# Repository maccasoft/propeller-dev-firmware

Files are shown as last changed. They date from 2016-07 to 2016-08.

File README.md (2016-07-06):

## Propeller Development Board

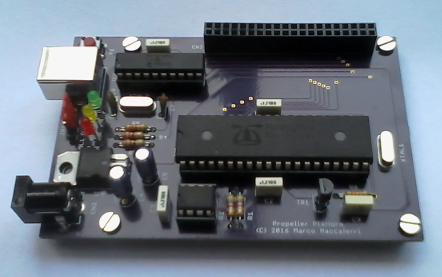
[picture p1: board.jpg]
The Board


This is my own version of a [Parallax Propeller](https://www.parallax.com) development board.

Uses a PIC microcontroller for the USB-Serial interface, can be powered from either USB or a dedicated power source, includes
an EEPROM to store the program and data, and provides a 2x20 pin header exposing all 32 I/O pins from the Propeller microcontroller,
power and control lines.

Compatible with all standard Propeller development tools.

**Parts List**

* R1 = 4.700 ohm 1/4 watt  
* R2 = 4.700 ohm 1/4 watt  
* R3 = 220 ohm 1/4 watt  
* R4 = 220 ohm 1/4 watt  
* R5 = 220 ohm 1/4 watt  
* R6 = 33.000 ohm 1/4 watt  
* C1 = 100.000 pF poli  
* C2 = 100.000 pF poli  
* C3 = 100.000 pF poli  
* C4 = 10 uF 63v elettr.  
* C5 = 10 uF 63v elettr.  
* C6 = 100.000 pF poli  
* C7 = 27 pF disc  
* C8 = 27 pF disc  
* C9 = 10.000 pF poli  
* DL1 = Red LED  
* DL2 = Yellow LED  
* DL3 = Green LED  
* XTAL1 = 5 MHz crystal  
* XTAL2 = 12 MHz crystal  
* IC1 = P8X32A  
* IC2 = 24LC512  
* IC3 = PIC18F14K50  
* IC4 = LM1117T-3.3  
* TR1 = Transistor NPN BC547  
* CN1 = USB-B connector  
* CN2 = 2.1mm DC power connector  
* CN3 = 2x20 pin header  
* JP1 = 1x3 pin header  
* P1 =  Button  

**JP1**

Power source selection:

```
+-+  
|1| USB  
|2| VIN  
|3| EXT  
+-+  
```

short pins 1-2 to power from USB  
short pins 2-3 to power from external source.

**CN3**

From top, P0/P1 are near the PIC/USB microcontroller.

```
+-------+-------+  
|     P0|P1     |  
|     P2|P3     |  
|     P4|P5     |  
|     P6|P7     |  
|     P8|P9     |  
|    P10|P11    |  
|    P12|P13    |  
|    P14|P15    |  
|    P16|P17    |  
|    P18|P19    |  
|    P20|P21    |  
|    P22|P23    |  
|    P24|P25    |  
|    P26|P27    |  
|SDA/P29|N.C.   |  
|SCL/P28|XI     |  
| TX/P30|RTS    |  
| RX/P31|CTS    |  
|  RESET|+3.3v  |  
|    GND|VIN    |  
+-------+-------+  
```

PCBs are shared on [OSH Park](https://oshpark.com) and can be ordered from there:
[https://oshpark.com/shared_projects/KALqBSpm](https://oshpark.com/shared_projects/KALqBSpm)

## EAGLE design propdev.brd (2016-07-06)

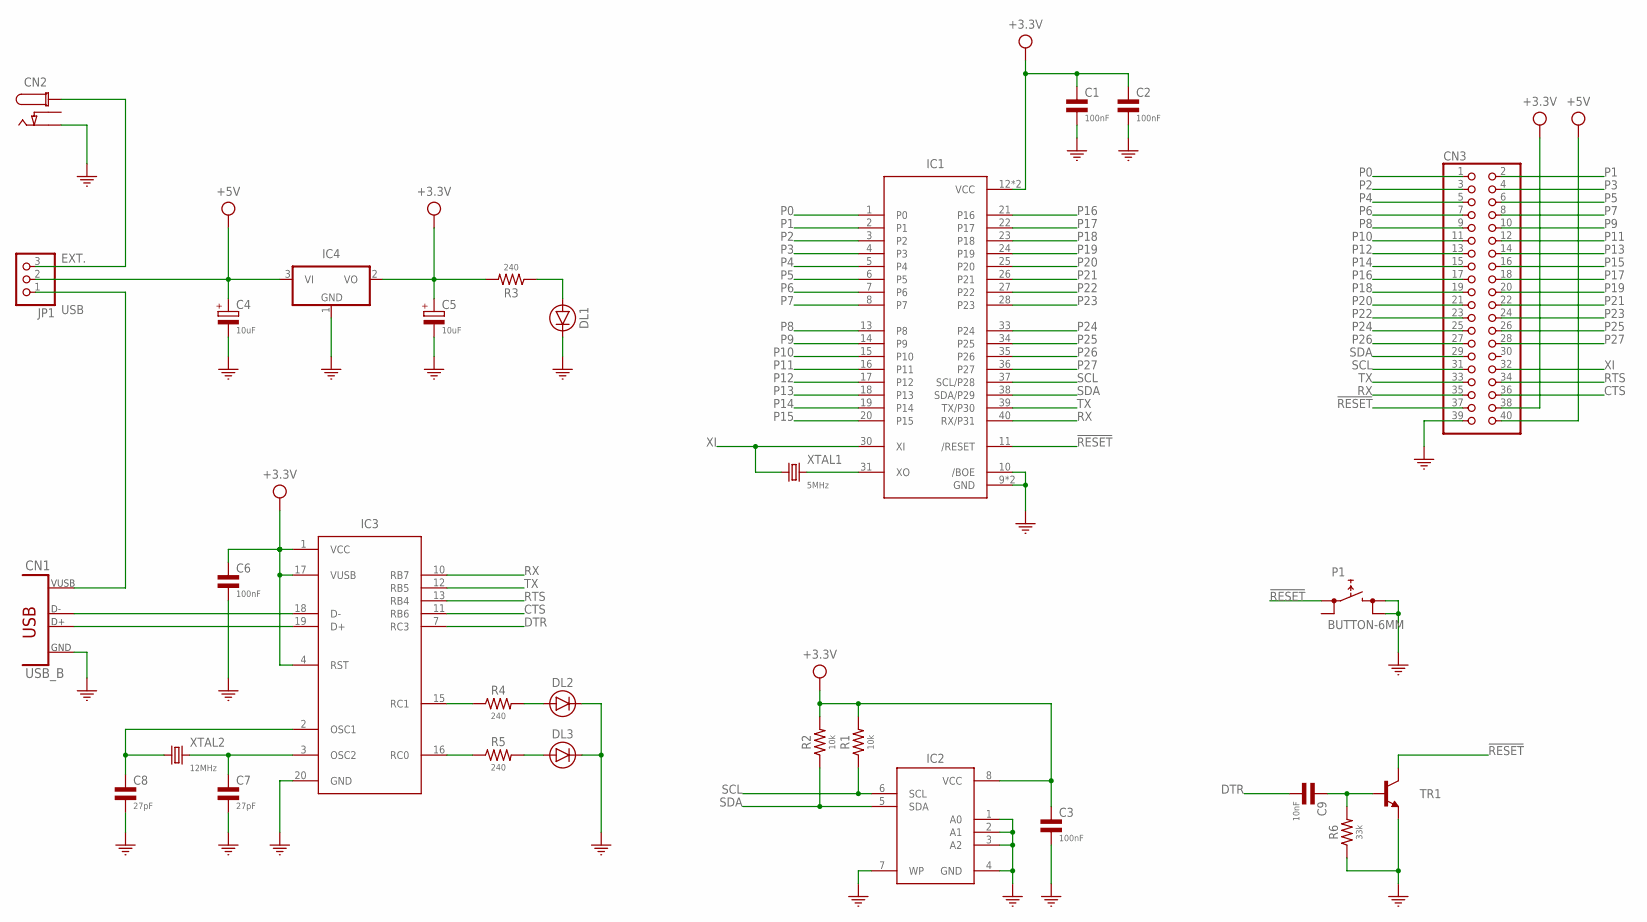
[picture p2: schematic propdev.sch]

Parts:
C1, C2, C3, C6: 100nF; C050-025X075
C4, C5: 10uF; E2,5-6
C7, C8: 27pF; C050-025X075
C9: 10nF; C050-025X075
CN1: USB_B; USB-B
CN2: DC_JACK; PJ-102A
CN3: PINHD-2X20B; 2X20B
DL1, DL2, DL3: LED-3MM; LED3MM
IC1: P8X32A; DIL40
IC2: 24LC512-I/P; DIL08
IC3: PIC18F14K50-I/P; DIL20
IC4: LM1117T-3.3; TO220H
JP1: PINHD-1X3; 1X03
P1: BUTTON-6MM; TL1105
R1, R2: 10k; 0207/10
R3, R4, R5: 240; 0207/10
R6: 33k; 0207/10
TR1: BC547; TO92
XTAL1: 5MHz; HC49/S
XTAL2: 12MHz; HC49/S

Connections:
!RESET!: CN3.37, IC1.11 (/RESET), P1.1 (0), TR1.3 (C)
+3.3V: C1.1, C2.1, C3.1, C5.+, C6.1, CN3.38, IC1.12 (VCC), IC1.32 (VCC), IC2.8 (VCC), IC3.1 (VCC), IC3.4 (RST), IC3.17 (VUSB), IC4.2 (VO), R1.2, R2.2, R3.2
+5V: C4.+, CN3.40, IC4.3 (VI), JP1.2
CTS: CN3.36, IC3.11 (RB6)
DTR: C9.2, IC3.7 (RC3)
EXT.: CN2.P1, JP1.3
GND: C1.2, C2.2, C3.2, C4.-, C5.-, C6.2, C7.2, C8.2, CN1.4 (GND), CN2.P3 (P2), CN3.39, DL1.K (C), DL2.K (C), DL3.K (C), IC1.9 (GND), IC1.10 (/BOE), IC1.29 (GND), IC2.1 (A0), IC2.2 (A1), IC2.3 (A2), IC2.4 (GND), IC2.7 (WP), IC3.20 (GND), IC4.1 (GND), P1.2 (1), P1.4 (1), R6.1, TR1.1 (E)
unnamed: IC3.16 (RC0), R5.1
unnamed: CN1.2 (D-), IC3.18 (D-)
unnamed: CN1.3 (D+), IC3.19 (D+)
unnamed: C7.1, IC3.3 (OSC2), XTAL2.2
unnamed: C8.1, IC3.2 (OSC1), XTAL2.1
unnamed: C9.1, R6.2, TR1.2 (B)
unnamed: DL2.A, R4.2
unnamed: DL3.A, R5.2
unnamed: IC3.15 (RC1), R4.1
unnamed: DL1.A, R3.1
unnamed: IC1.31 (XO), XTAL1.2
P0: CN3.1, IC1.1 (P0)
P1: CN3.2, IC1.2 (P1)
P2: CN3.3, IC1.3 (P2)
P3: CN3.4, IC1.4 (P3)
P4: CN3.5, IC1.5 (P4)
P5: CN3.6, IC1.6 (P5)
P6: CN3.7, IC1.7 (P6)
P7: CN3.8, IC1.8 (P7)
P8: CN3.9, IC1.13 (P8)
P9: CN3.10, IC1.14 (P9)
P10: CN3.11, IC1.15 (P10)
P11: CN3.12, IC1.16 (P11)
P12: CN3.13, IC1.17 (P12)
P13: CN3.14, IC1.18 (P13)
P14: CN3.15, IC1.19 (P14)
P15: CN3.16, IC1.20 (P15)
P16: CN3.17, IC1.21 (P16)
P17: CN3.18, IC1.22 (P17)
P18: CN3.19, IC1.23 (P18)
P19: CN3.20, IC1.24 (P19)
P20: CN3.21, IC1.25 (P20)
P21: CN3.22, IC1.26 (P21)
P22: CN3.23, IC1.27 (P22)
P23: CN3.24, IC1.28 (P23)
P24: CN3.25, IC1.33 (P24)
P25: CN3.26, IC1.34 (P25)
P26: CN3.27, IC1.35 (P26)
P27: CN3.28, IC1.36 (P27)
RTS: CN3.34, IC3.13 (RB4)
RX: CN3.35, IC1.40 (RX/P31), IC3.10 (RB7)
SCL: CN3.31, IC1.37 (SCL/P28), IC2.6 (SCL), R1.1
SDA: CN3.29, IC1.38 (SDA/P29), IC2.5 (SDA), R2.1
TX: CN3.33, IC1.39 (TX/P30), IC3.12 (RB5)
USB: CN1.1 (VUSB), JP1.1
XI: CN3.32, IC1.30 (XI), XTAL1.1

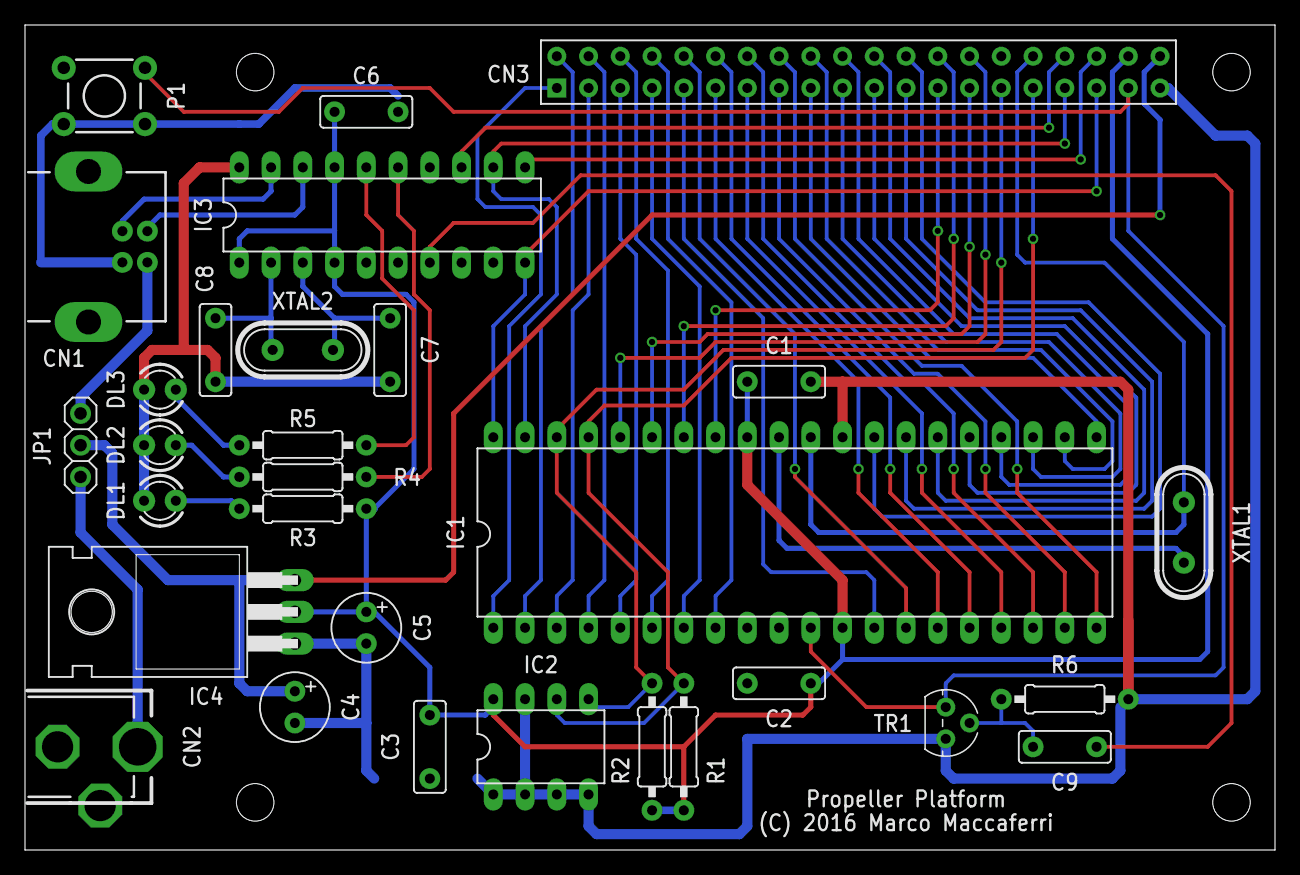
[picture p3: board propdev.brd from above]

Board: 2 copper layers, 100.0 x 66.0 mm, 30 parts (0 on the bottom side), 53 nets.

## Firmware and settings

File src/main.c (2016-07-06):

/********************************************************************
 Software License Agreement:

 The software supplied herewith by Microchip Technology Incorporated
 (the "Company") for its PIC(R) Microcontroller is intended and
 supplied to you, the Company's customer, for use solely and
 exclusively on Microchip PIC Microcontroller products. The
 software is owned by the Company and/or its supplier, and is
 protected under applicable copyright laws. All rights are reserved.
 Any use in violation of the foregoing restrictions may subject the
 user to criminal sanctions under applicable laws, as well as to
 civil liability for the breach of the terms and conditions of this
 license.

 THIS SOFTWARE IS PROVIDED IN AN "AS IS" CONDITION. NO WARRANTIES,
 WHETHER EXPRESS, IMPLIED OR STATUTORY, INCLUDING, BUT NOT LIMITED
 TO, IMPLIED WARRANTIES OF MERCHANTABILITY AND FITNESS FOR A
 PARTICULAR PURPOSE APPLY TO THIS SOFTWARE. THE COMPANY SHALL NOT,
 IN ANY CIRCUMSTANCES, BE LIABLE FOR SPECIAL, INCIDENTAL OR
 CONSEQUENTIAL DAMAGES, FOR ANY REASON WHATSOEVER.
 *******************************************************************/

/** INCLUDES *******************************************************/
#include "system.h"
#include "system_config.h"

#include "app_device_cdc_basic.h"
#include "app_led_usb_status.h"

#include "usb.h"
#include "usb_device.h"
#include "usb_device_cdc.h"

/********************************************************************
 * Function:        void main(void)
 *
 * PreCondition:    None
 *
 * Input:           None
 *
 * Output:          None
 *
 * Side Effects:    None
 *
 * Overview:        Main program entry point.
 *
 * Note:            None
 *******************************************************************/
MAIN_RETURN main(void)
{
    SYSTEM_Initialize(SYSTEM_STATE_USB_START);

    USBDeviceInit();
    USBDeviceAttach();
    
    while(1)
    {
        SYSTEM_Tasks();

        #if defined(USB_POLLING)
            // Interrupt or polling method.  If using polling, must call
            // this function periodically.  This function will take care
            // of processing and responding to SETUP transactions
            // (such as during the enumeration process when you first
            // plug in).  USB hosts require that USB devices should accept
            // and process SETUP packets in a timely fashion.  Therefore,
            // when using polling, this function should be called
            // regularly (such as once every 1.8ms or faster** [see
            // inline code comments in usb_device.c for explanation when
            // "or faster" applies])  In most cases, the USBDeviceTasks()
            // function does not take very long to execute (ex: <100
            // instruction cycles) before it returns.
            USBDeviceTasks();
        #endif


        /* If the USB device isn't configured yet, we can't really do anything
         * else since we don't have a host to talk to.  So jump back to the
         * top of the while loop. */
        if( USBGetDeviceState() < CONFIGURED_STATE )
        {
            /* Jump back to the top of the while loop. */
            continue;
        }

        /* If we are currently suspended, then we need to see if we need to
         * issue a remote wakeup.  In either case, we shouldn't process any
         * keyboard commands since we aren't currently communicating to the host
         * thus just continue back to the start of the while loop. */
        if( USBIsDeviceSuspended()== true )
        {
            /* Jump back to the top of the while loop. */
            continue;
        }

        //Application specific tasks
        APP_DeviceCDCEmulatorTasks();

    }//end while
}//end main




bool USER_USB_CALLBACK_EVENT_HANDLER(USB_EVENT event, void *pdata, uint16_t size)
{
    switch( (int) event )
    {
        case EVENT_TRANSFER:
            break;

        case EVENT_SOF:
            /* We are using the SOF as a timer to time the LED indicator.  Call
             * the LED update function here. */
            APP_LEDUpdateUSBStatus();
            break;

        case EVENT_SUSPEND:
            /* Update the LED status for the suspend event. */
            APP_LEDUpdateUSBStatus();
            break;

        case EVENT_RESUME:
            /* Update the LED status for the resume event. */
            APP_LEDUpdateUSBStatus();
            break;

        case EVENT_CONFIGURED:
            /* When the device is configured, we can (re)initialize the 
             * demo code. */
            APP_DeviceCDCEmulatorInitialize();
            break;

        case EVENT_SET_DESCRIPTOR:
            break;

        case EVENT_EP0_REQUEST:
            /* We have received a non-standard USB request.  The HID driver
             * needs to check to see if the request was for it. */
            USBCheckCDCRequest();
            break;

        case EVENT_BUS_ERROR:
            break;

        case EVENT_TRANSFER_TERMINATED:
            break;

        default:
            break;
    }
    return true;
}

/*******************************************************************************
 End of File
*/

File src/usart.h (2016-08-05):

/********************************************************************
 Software License Agreement:

 The software supplied herewith by Microchip Technology Incorporated
 (the "Company") for its PIC(R) Microcontroller is intended and
 supplied to you, the Company's customer, for use solely and
 exclusively on Microchip PIC Microcontroller products. The
 software is owned by the Company and/or its supplier, and is
 protected under applicable copyright laws. All rights are reserved.
 Any use in violation of the foregoing restrictions may subject the
 user to criminal sanctions under applicable laws, as well as to
 civil liability for the breach of the terms and conditions of this
 license.

 THIS SOFTWARE IS PROVIDED IN AN "AS IS" CONDITION. NO WARRANTIES,
 WHETHER EXPRESS, IMPLIED OR STATUTORY, INCLUDING, BUT NOT LIMITED
 TO, IMPLIED WARRANTIES OF MERCHANTABILITY AND FITNESS FOR A
 PARTICULAR PURPOSE APPLY TO THIS SOFTWARE. THE COMPANY SHALL NOT,
 IN ANY CIRCUMSTANCES, BE LIABLE FOR SPECIAL, INCIDENTAL OR
 CONSEQUENTIAL DAMAGES, FOR ANY REASON WHATSOEVER.
 *******************************************************************/

#ifndef USART_H
#define USART_H

#include <stdbool.h>

#define CLOCK_FREQ 48000000
#define GetSystemClock() CLOCK_FREQ

#define UART_ENABLE   RCSTAbits.SPEN

#define UART_TRISTx   TRISBbits.TRISB7
#define UART_TRISRx   TRISBbits.TRISB5
#define UART_Tx       PORTBbits.RB7
#define UART_Rx       PORTBbits.RB5

// Use following only for Hardware Flow Control
#define UART_DTS      PORTAbits.RA3
#define UART_DTR      LATCbits.LATC3
#define UART_RTS      LATBbits.LATB4
#define UART_CTS      PORTBbits.RB6

#define mEnableRxPU() {WPUB5 = 1;} // Enable Rx pin pull-up

#define mInitRTSPin() {TRISBbits.TRISB4 = 0;}   //Configure RTS as a digital output.
#define mInitCTSPin() {TRISBbits.TRISB6 = 1;}   //Configure CTS as a digital input.  (Make sure pin is digital if ANxx functions is present on the pin)
#define mInitDTSPin() {}//{TRISAbits.TRISA3 = 1;}   //Configure DTS as a digital input.  (Make sure pin is digital if ANxx functions is present on the pin)
#define mInitDTRPin() {TRISCbits.TRISC3 = 0;}   //Configure DTR as a digital output.




/*********************************************************************
* Function: void USART_Initialize(void);
*
* Overview: Initializes USART (RS-232 port)
*
* PreCondition: None
*
* Input: None
*
* Output: None
*
********************************************************************/
void USART_Initialize();

/******************************************************************************
 * Function:        void USART_putcUSART(char c)
 *
 * PreCondition:    None
 *
 * Input:           char c - character to print to the UART
 *
 * Output:          None
 *
 * Side Effects:    None
 *
 * Overview:        Print the input character to the UART
 *
 * Note:
 *
 *****************************************************************************/
void USART_putcUSART(char);

/******************************************************************************
 * Function:        void USART_mySetLineCodingHandler(void)
 *
 * PreCondition:    USB_CDC_SET_LINE_CODING_HANDLER mySetLineCodingHandler is defined
 *
 * Input:           None
 *
 * Output:          None
 *
 * Side Effects:    None
 *
 * Overview:        This function gets called when a SetLineCoding command
 *                  is sent on the bus.  This function will evaluate the request
 *                  and determine if the application should update the baudrate
 *                  or not.
 *
 * Note:
 *
 *****************************************************************************/
void USART_mySetLineCodingHandler(void);

/******************************************************************************
 * Function:        unsigned char USART_getcUSART()
 *
 * PreCondition:    None
 *
 * Input:           None
 *
 * Output:          unsigned char c - character to received on the UART
 *
 * Side Effects:    None
 *
 * Overview:        Get the input character from the UART
 *
 * Note:
 *
 *****************************************************************************/
unsigned char USART_getcUSART(void);

#endif //USART_H

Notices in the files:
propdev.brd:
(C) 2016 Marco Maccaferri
